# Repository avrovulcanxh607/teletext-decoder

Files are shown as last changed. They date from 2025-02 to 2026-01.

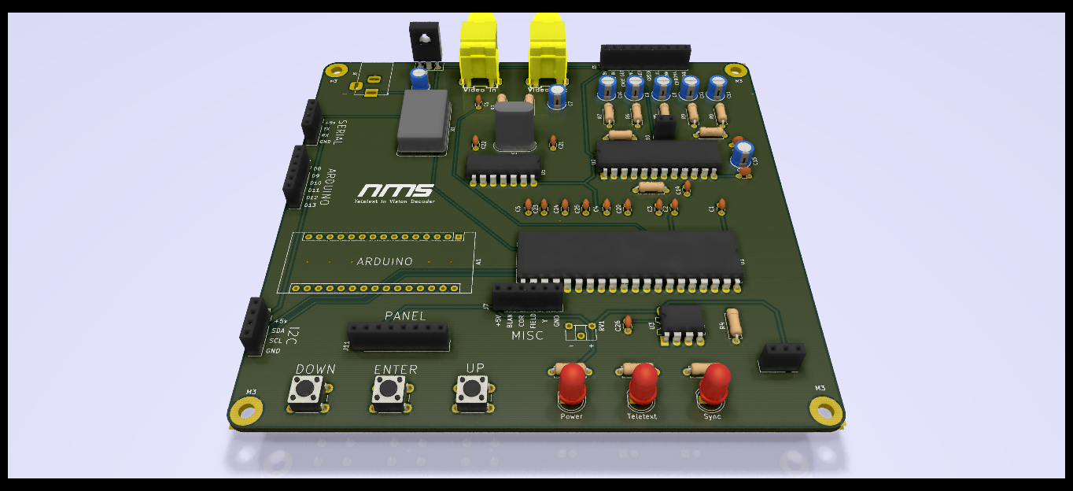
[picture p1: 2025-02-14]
PCB Files/COMPONENTS.png

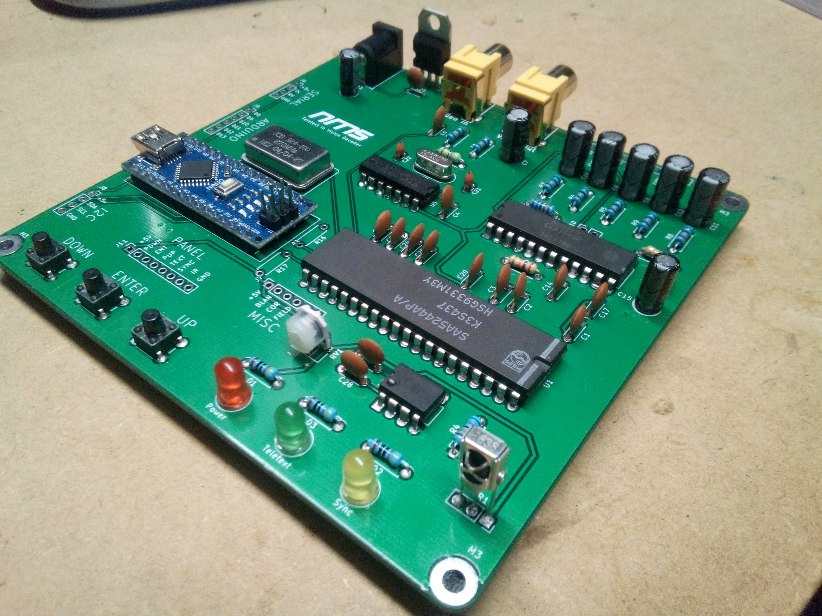
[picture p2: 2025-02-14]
PCB Files/IMG_20200507_191400.jpg

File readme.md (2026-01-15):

# Teletext In Vision Decoder Board

This repo is an attempt to open-source my teletext decoder.

It was originally designed, tested, and even a few were sold by me in 2019.

You can see the [original product page for it on my website](https://www.nathanmediaservices.co.uk/invision/).

You are now free to do whatever you like with this design and the firmware for it - except selling it. You are **expressly forbidden** to use these designs to create a product that you then go on to resell, unless I have given you written permission otherwise.

Disclaimer: the design and firmwares are offered completely as-is, with no warranty of any kind. I will no longer be offering support or assistance on this project, if you want to build one you must figure it out from the resources provided here. 

## Why are there so many different firmwares?

Because I have built various slightly different boards into different projects and cases for different purposes, and with different ancillaries. For example, there are code bases here which support LCD screens, IR remotes, thumbwheel selectors, serial remotes, etc. You'll probably need to try a few and modify them to suit your needs.

## PCB Versions
There are three total versions of the decoder PCB. The first version was a prototype, and features a number of mistakes - I therefore do not recommend using it. Unless you're a complete masochist.

The first revision fixes the mistakes on the prototype and is ready to use. 

The second revision swaps the Arduino Nano for a standalone ATMega328(p) chip. This makes it cheaper and easier for manufacture, but harder for programming/debugging - therefore I don't recommend this revision for the novice.

## Notes
Depending on how you configure the ATMega328(p) in revision 2, you may omit the crystal Y2 and associated tuning capacitors.

You may also omit R17 and R18 - these are I2C pullup resistors, and I have yet to find a need for more pullup than already onboard the microcontroller.

You need not install the output circuitry for the S-Video or RGB outputs if you don't need those - on the other hand, if you only intend to use the RGB output you can probably get rid of the entire PAL coder circuit and just bridge the chip's RGB directly to the outputs.

Really, you only actually *need* the teletext decoder, video input circuitry, and the microcontroller - the rest depends on what you're using it for! I have shipped some very bare boards in specific circumstances!

Similarly, the board is designed to take a 9-15v DC input and regulate it down to 5v for operation - however, the LM7805 should really have a heatsink and can be unreliable. Personally I always bridge the regulator out and supply 5v directly from an external supply.

If you are having trouble getting colour to work on the PAL CVBS or S-Video outputs, you need to check the colour subcarrier frequency. Your crystal may require slightly different tuning capacitors. However I have found most TVs to be very forgiving of the subcarrier frequency.

If you do decide to do something cool with this design, please consider posting photos of it to Bluesky and tagging "@nmsni.co.uk", I would love to see it!

Also... consider kicking a quid or two my way at [Ko-Fi](https://ko-fi.com/avrovulcanxh607). It took a fair bit of time to figure this out.

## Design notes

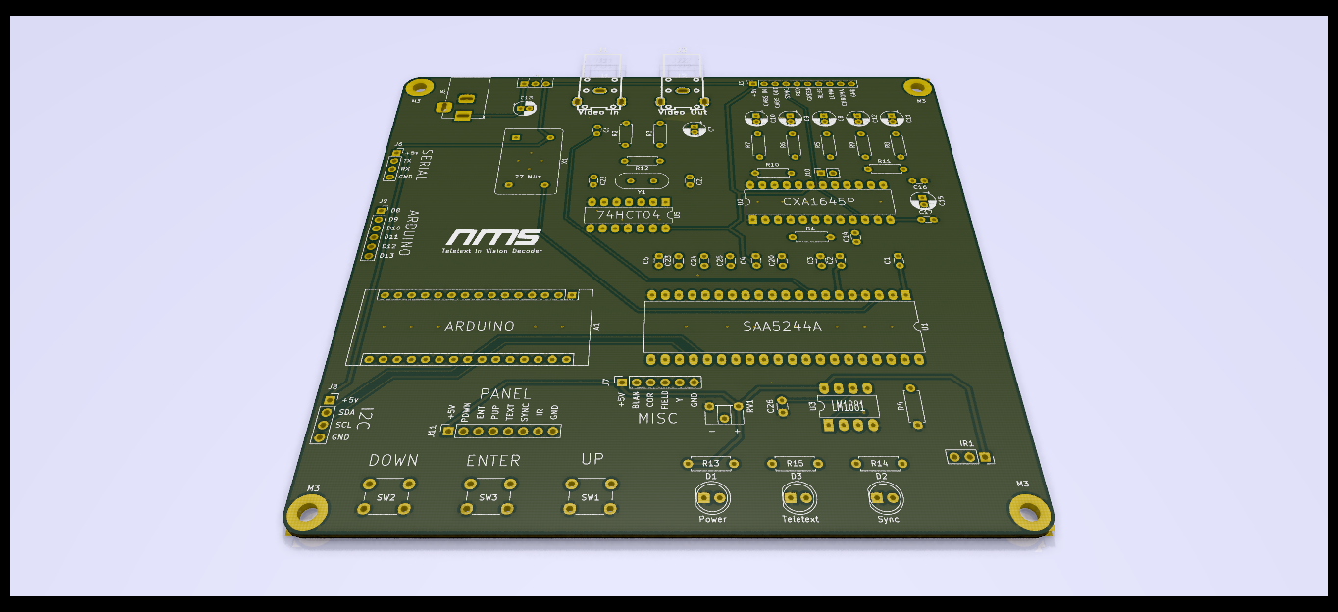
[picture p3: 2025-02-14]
PCB Files/BARE BOARD.png

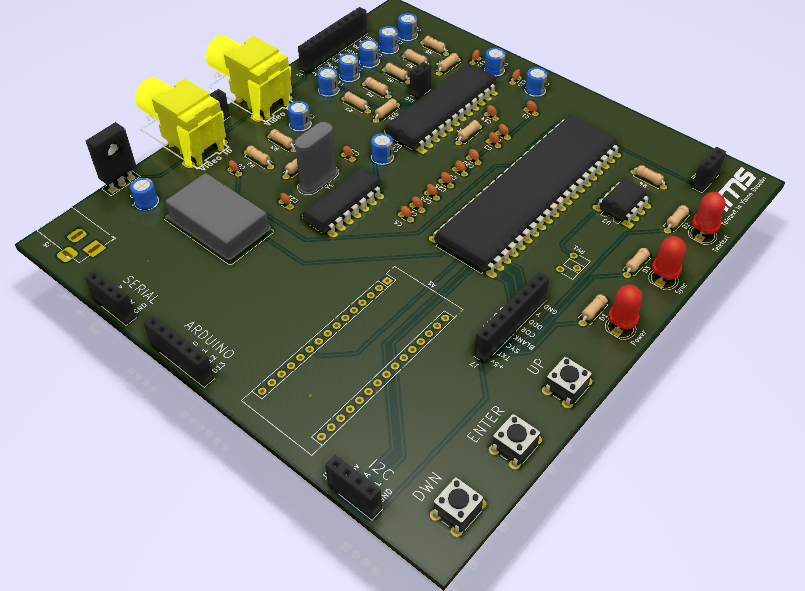
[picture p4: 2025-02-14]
PCB Files/Teletext In-Vision Decoder.png

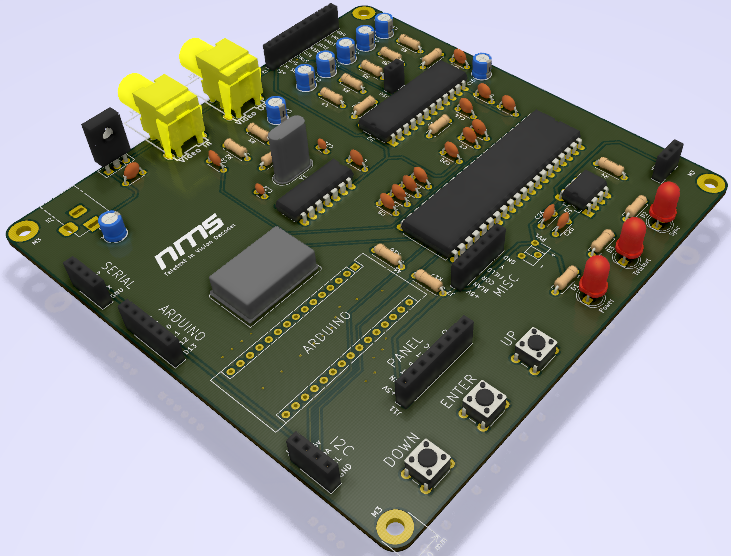
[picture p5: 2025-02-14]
PCB Files/pcbfordiag.png

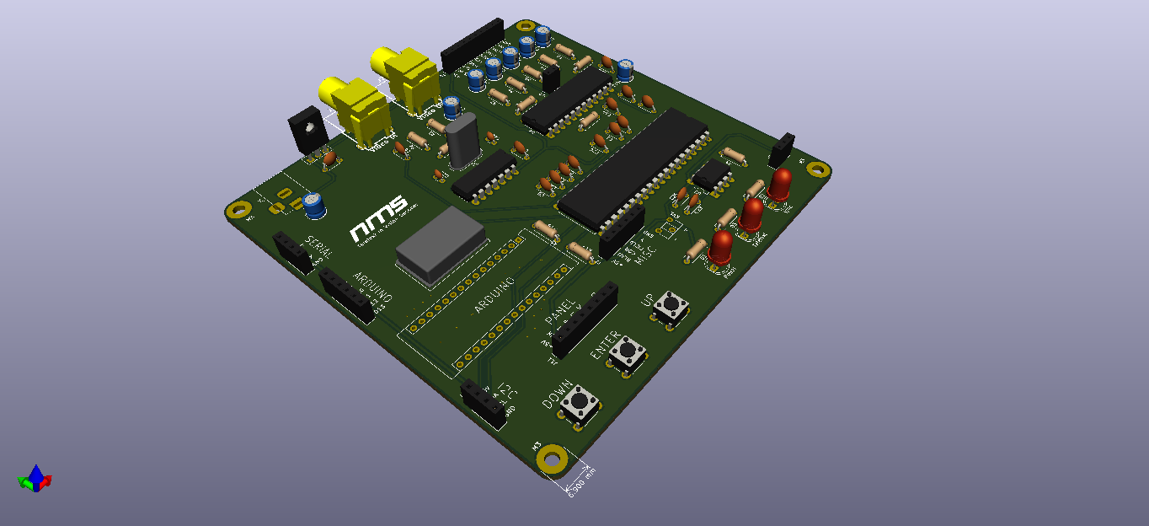
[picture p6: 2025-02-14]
PCB Files/pcbfordiag2.png

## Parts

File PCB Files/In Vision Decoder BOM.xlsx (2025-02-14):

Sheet: Per Reference
ref | value5 | footprint | part | description | names | tstamps6 | tstamp | datasheet | lib7 | part8 | alias | description9 | docs | fp | field | name10 | num | name11 | type | logical | uri | code | name12 | ref13 | pin
C1 | 100nF | Capacitor_THT:C_Disc_D3.0mm_W1.6mm_P2.50mm | C | Unpolarized capacitor
C14 | 100nF | Capacitor_THT:C_Disc_D3.0mm_W1.6mm_P2.50mm | C | Unpolarized capacitor
C16 | 100nF | Capacitor_THT:C_Disc_D3.0mm_W1.6mm_P2.50mm | C | Unpolarized capacitor
C17 | 100nF | Capacitor_THT:C_Disc_D3.0mm_W1.6mm_P2.50mm | C | Unpolarized capacitor
C2 | 100nF | Capacitor_THT:C_Disc_D3.0mm_W1.6mm_P2.50mm | C | Unpolarized capacitor
C20 | 100nF | Capacitor_THT:C_Disc_D3.0mm_W1.6mm_P2.50mm | C | Unpolarized capacitor
C23 | 100nF | Capacitor_THT:C_Disc_D3.0mm_W1.6mm_P2.50mm | C | Unpolarized capacitor
C24 | 100nF | Capacitor_THT:C_Disc_D3.0mm_W1.6mm_P2.50mm | C | Unpolarized capacitor
C25 | 100nF | Capacitor_THT:C_Disc_D3.0mm_W1.6mm_P2.50mm | C | Unpolarized capacitor
C26 | 100nf | Capacitor_THT:C_Disc_D3.0mm_W1.6mm_P2.50mm | C | Unpolarized capacitor
C27 | 100nF | Capacitor_THT:C_Disc_D3.0mm_W1.6mm_P2.50mm | C | Unpolarized capacitor
C3 | 100nF | Capacitor_THT:C_Disc_D3.0mm_W1.6mm_P2.50mm | C | Unpolarized capacitor
C4 | 100nF | Capacitor_THT:C_Disc_D3.0mm_W1.6mm_P2.50mm | C | Unpolarized capacitor
C5 | 100nF | Capacitor_THT:C_Disc_D3.0mm_W1.6mm_P2.50mm | C | Unpolarized capacitor
C6 | 100nF | Capacitor_THT:C_Disc_D3.0mm_W1.6mm_P2.50mm | C | Unpolarized capacitor
R16 | 10k | Resistor_THT:R_Axial_DIN0207_L6.3mm_D2.5mm_P7.62mm_Horizontal | R | Resistor
R17 | 10k | Resistor_THT:R_Axial_DIN0207_L6.3mm_D2.5mm_P7.62mm_Horizontal | R | Resistor
RV1 | 10k | Potentiometer_THT:Potentiometer_ACP_CA6-H2,5_Horizontal | R_POT | Potentiometer
C13 | 10uF | Capacitor_THT:CP_Radial_D5.0mm_P2.00mm | CP | Polarized capacitor
C15 | 10uF | Capacitor_THT:CP_Radial_D5.0mm_P2.00mm | CP | Polarized capacitor
R10 | 16k | Resistor_THT:R_Axial_DIN0207_L6.3mm_D2.5mm_P7.62mm_Horizontal | R | Resistor
R13 | 1k | Resistor_THT:R_Axial_DIN0207_L6.3mm_D2.5mm_P7.62mm_Horizontal | R | Resistor
R14 | 1k | Resistor_THT:R_Axial_DIN0207_L6.3mm_D2.5mm_P7.62mm_Horizontal | R | Resistor
R15 | 1k | Resistor_THT:R_Axial_DIN0207_L6.3mm_D2.5mm_P7.62mm_Horizontal | R | Resistor
C10 | 220uF | Capacitor_THT:CP_Radial_D5.0mm_P2.00mm | CP | Polarized capacitor
C11 | 220uF | Capacitor_THT:CP_Radial_D5.0mm_P2.00mm | CP | Polarized capacitor
C12 | 220uF | Capacitor_THT:CP_Radial_D5.0mm_P2.00mm | CP | Polarized capacitor
C7 | 220uF | Capacitor_THT:CP_Radial_D5.0mm_P2.00mm | CP | Polarized capacitor
C8 | 220uF | Capacitor_THT:CP_Radial_D5.0mm_P2.00mm | CP | Polarized capacitor
C9 | 220uF | Capacitor_THT:CP_Radial_D5.0mm_P2.00mm | CP | Polarized capacitor
R1 | 27k | Resistor_THT:R_Axial_DIN0207_L6.3mm_D2.5mm_P7.62mm_Horizontal | R | Resistor
C21 | 33pF | Capacitor_THT:C_Disc_D3.0mm_W1.6mm_P2.50mm | C | Unpolarized capacitor
C22 | 33pF | Capacitor_THT:C_Disc_D3.0mm_W1.6mm_P2.50mm | C | Unpolarized capacitor
Y1 | 4.43 MHz | Crystal:Crystal_HC49-U_Vertical | Crystal | Two pin crystal
R12 | 4.7M | Resistor_THT:R_Axial_DIN0207_L6.3mm_D2.5mm_P7.62mm_Horizontal | R | Resistor
R11 | 47k | Resistor_THT:R_Axial_DIN0207_L6.3mm_D2.5mm_P7.62mm_Horizontal | R | Resistor
R4 | 680k | Resistor_THT:R_Axial_DIN0207_L6.3mm_D2.5mm_P7.62mm_Horizontal | R | Resistor
U5 | 74HCT04 | Package_DIP:DIP-14_W7.62mm_LongPads | 74HCT04 | Hex Inverter
R2 | 75R | Resistor_THT:R_Axial_DIN0207_L6.3mm_D2.5mm_P7.62mm_Horizontal | R | Resistor
R3 | 75R | Resistor_THT:R_Axial_DIN0207_L6.3mm_D2.5mm_P7.62mm_Horizontal | R | Resistor
R5 | 75R | Resistor_THT:R_Axial_DIN0207_L6.3mm_D2.5mm_P7.62mm_Horizontal | R | Resistor
R6 | 75R | Resistor_THT:R_Axial_DIN0207_L6.3mm_D2.5mm_P7.62mm_Horizontal | R | Resistor
R7 | 75R | Resistor_THT:R_Axial_DIN0207_L6.3mm_D2.5mm_P7.62mm_Horizontal | R | Resistor
R8 | 75R | Resistor_THT:R_Axial_DIN0207_L6.3mm_D2.5mm_P7.62mm_Horizontal | R | Resistor
R9 | 75R | Resistor_THT:R_Axial_DIN0207_L6.3mm_D2.5mm_P7.62mm_Horizontal | R | Resistor
J9 | ARDUINO | Connector_PinSocket_2.54mm:PinSocket_1x06_P2.54mm_Vertical | Conn_01x06_Male
A1 | Arduino_Nano_v3.x | Module:Arduino_Nano | Arduino_Nano_v3.x | Arduino Nano v3.x
U2 | CXA1645P | Package_DIP:DIP-24_W10.16mm_LongPads | CXA1645P
X1 | CXO_DIP14 | Oscillator:Oscillator_DIP-14 | CXO_DIP14 | Crystal Clock Oscillator, DIP14-style metal package
SW3 | ENTER | Button_Switch_THT:SW_PUSH_6mm | SW_Push | Push button switch, generic, two pins
J8 | I2C | Connector_PinSocket_2.54mm:PinSocket_1x04_P2.54mm_Vertical | Conn_01x04_Male
IR1 | IR Receiver | Connector_PinSocket_2.54mm:PinSocket_1x03_P2.54mm_Vertical | Conn_01x03_Male
U4 | L7805 | Package_TO_SOT_THT:TO-126-3_Vertical | L7805 | Positive 1.5A 35V Linear Regulator, Fixed Output 5V, TO-220/TO-263/TO-252
U3 | LM1881 | Package_DIP:DIP-8_W7.62mm_LongPads | LM1881
J7 | MISC | Connector_PinSocket_2.54mm:PinSocket_1x06_P2.54mm_Vertical | Conn_01x06_Male
J11 | PANEL | Connector_PinSocket_2.54mm:PinSocket_1x08_P2.54mm_Vertical | Conn_01x08_Male
SW2 | PDWN | Button_Switch_THT:SW_PUSH_6mm | SW_Push | Push button switch, generic, two pins
D1 | POWER | LED_THT:LED_D5.0mm | LED | Light emitting diode
J5 | POWER IN | Connector_BarrelJack:BarrelJack_Horizontal | Barrel_Jack_MountingPin | DC Barrel Jack with a mounting pin
SW1 | PUP | Button_Switch_THT:SW_PUSH_6mm | SW_Push | Push button switch, generic, two pins
U1 | SAA5244A | Package_DIP:DIP-40_W15.24mm_LongPads | SAA5244A
J6 | SERIAL | Connector_PinSocket_2.54mm:PinSocket_1x04_P2.54mm_Vertical | Conn_01x04_Male
D2 | SYNC | LED_THT:LED_D5.0mm | LED | Light emitting diode
D3 | TEXT | LED_THT:LED_D5.0mm | LED | Light emitting diode
J3 | VIDEO | Connector_PinSocket_2.54mm:PinSocket_1x10_P2.54mm_Vertical | Conn_01x10_Male
J1 | Video In | AV Connectors:rca_yellow | Conn_Coaxial | coaxial connector (BNC, SMA, SMB, SMC, Cinch/RCA, ...)
J2 | Video Out | AV Connectors:rca_yellow | Conn_Coaxial | coaxial connector (BNC, SMA, SMB, SMC, Cinch/RCA, ...)
J10 | Y TRAP | Connector_PinSocket_2.54mm:PinSocket_1x02_P2.54mm_Vertical | Conn_01x02_Male

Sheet: Per Value
 | Boards In Run: | 4 | Boards Completed: | 0 | Boards Sold: | 0
Ref | Value | Required (per board) | Required (per run) | Available | Excess/Short | Price (per run) | Price (per board)
C1 C2 C3 C4 C5 C6 C14 C16 C17 C20 C23 C24 C25 C26 C27 C28 | 100nF | 15 | 60 | 100 | 40 | £1.98 | £0.49
C13 C15 | 10uF | 2 | 8 | 25 | 17 | £0.99 | £0.25
C7 C8 C9 C10 C11 C12 | 220uF | 6 | 24 | 50 | 26 | £2.28 | £0.57
C21 C22 | 33pF | 2 | 8 | 20 | 12 | £1.29 | £0.32
R2 R3 R5 R6 R7 R8 R9 | 75R | 7 | 28 | 25 | -3 | £0.99 | £0.25
R13 R14 R15 | 1K | 3 | 12 | 24 | 12 | £0.99 | £0.25
R16 R17 | 10K | 2 | 8 | 0 | -8 | £0.99 | £0.25
R10 | 16K | 1 | 4 | 16 | 12 | £0.99 | £0.25
R1 | 27K | 1 | 4 | 12 | 8 | £0.99 | £0.25
R12 | 4.7M | 1 | 4 | 0 | -4 | £0.99 | £0.25
R11 | 47K | 1 | 4 | 7 | 3 | £0.99 | £0.25
R4 | 680K | 1 | 4 | 21 | 17 | £0.99 | £0.25
RV1 | 10K | 1 | 4 | 3 | -1 | £0.99 | £0.25
CXA1645P |  | 1 | 4 | 3 | -1 | £5.00 | £1.25
L7805 |  | 1 | 4 | 5 | 1 | £1.66 | £0.41
LM1881 |  | 1 | 4 | 4 | 0 | £5.00 | £1.25
SAA5244A |  | 1 | 4 | 7 | 3 | £22.16 | £5.54
74HCT04 |  | 1 | 4 | 10 | 6 | £2.24 | £0.56
Arduino Nano |  | 1 | 4 | 10 | 6 | £17.01 | £4.25
IR Receiver |  | 1 | 4 | 5 | 1 | £2.10 | £0.53
27MHz Oscillator |  | 1 | 4 | 5 | 1 | £14.90 | £3.73
4.43MHz Crystal |  | 1 | 4 | 6 | 2 | £12.24 | £3.06
LEDs |  | 3 | 12 | 30 | 18 | £5.00 | £1.25
Tactile Buttons |  | 3 | 12 | 20 | 8 | £3.49 | £0.87
Power Sockets |  | 1 | 4 | 10 | 6 | £3.49 | £0.87
Phono Sockets |  | 2 | 8 | 10 | 2 | £2.99 | £0.75
PCB |  | 1 | 4 | 10 | 6 | £13.39 | £3.35
TOTAL |  | 62.00 |  |  |  | £126.12 | £31.53
Recommended Price given profit margin |  | £215 | £53.75
Profit at recommended price |  | £88.88
Profit margin | 1.70
 |  |  | £5.00 | 1
 | Parts | Shipping | Me
Percentages | 0.587 | 0.023 | 0.390

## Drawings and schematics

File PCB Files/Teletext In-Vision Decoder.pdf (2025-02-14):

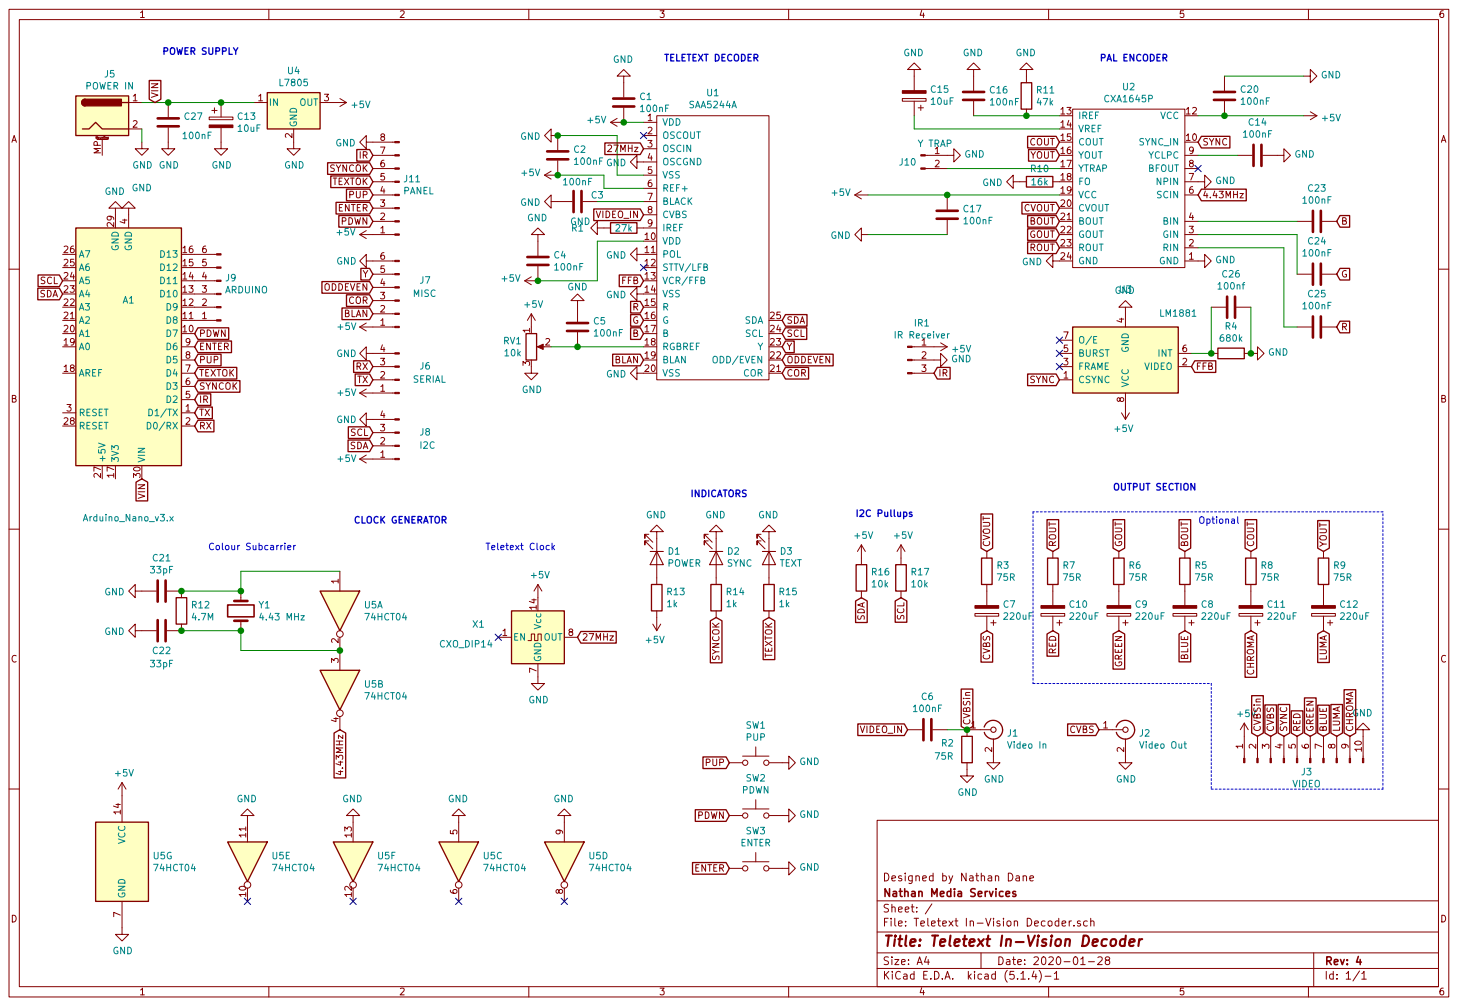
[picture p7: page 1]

FFB ROUTROUT GOUT SYNC

Optional I2C Pullups Teletext Clock

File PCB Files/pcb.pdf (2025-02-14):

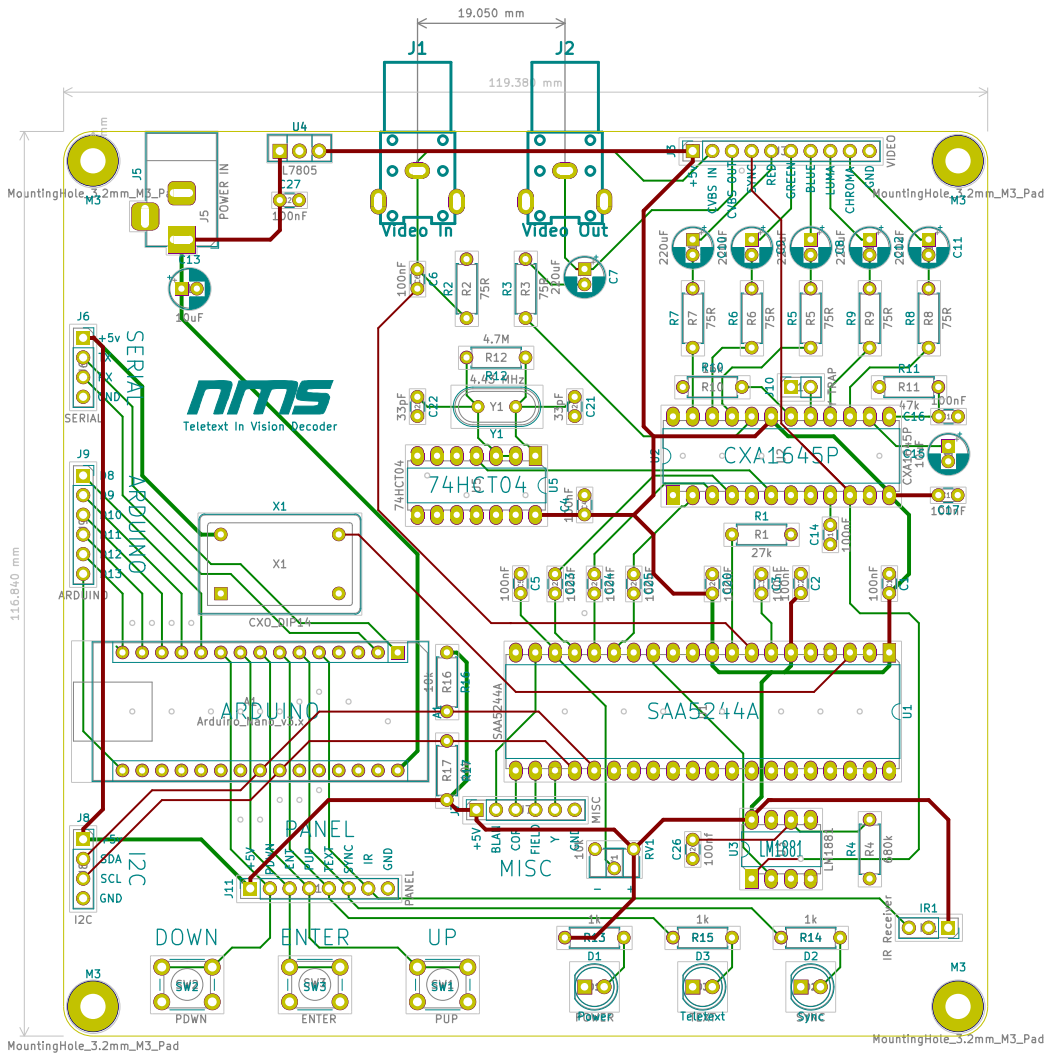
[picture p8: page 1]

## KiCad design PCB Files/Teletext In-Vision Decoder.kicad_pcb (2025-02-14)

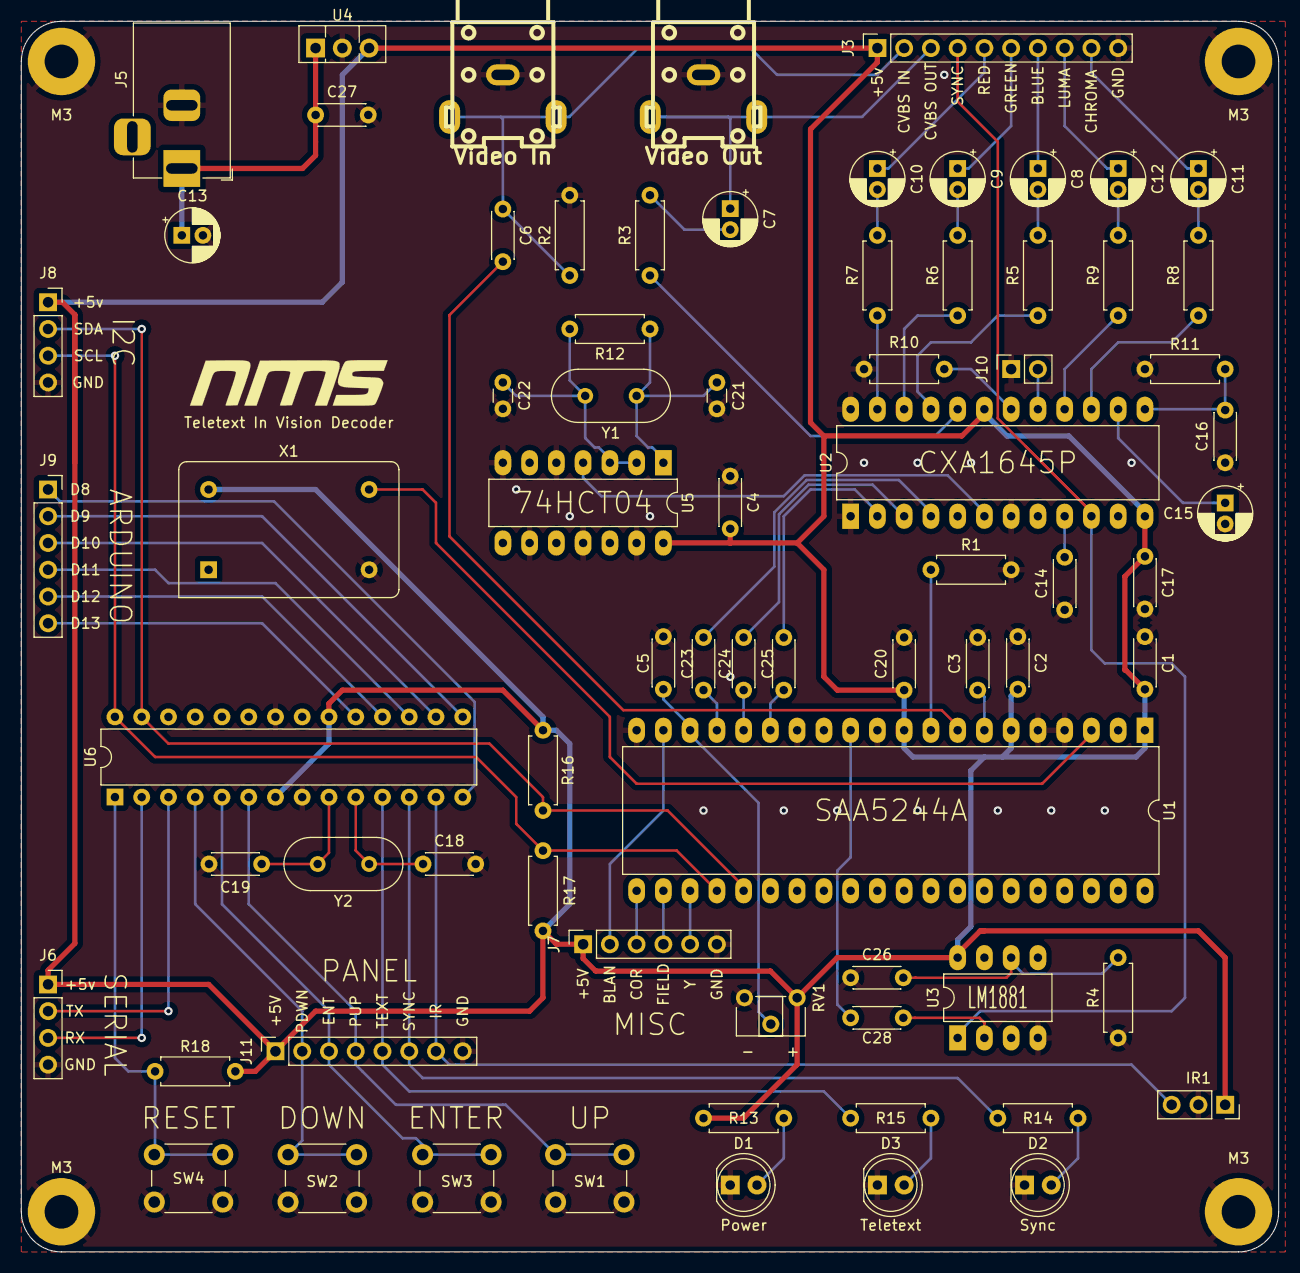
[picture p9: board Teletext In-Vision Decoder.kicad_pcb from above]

Board: 2 copper layers, 119.4 x 116.8 mm, 78 parts (0 on the bottom side), 71 nets.

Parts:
C1, C2, C3, C4, C5, C6, C14, C16, C17, C20, C23, C24, C25, C27, C28: 100nF; C_Disc_D4.3mm_W1.9mm_P5.00mm
C7, C8, C9, C10, C11, C12: 220uF; CP_Radial_D5.0mm_P2.00mm
C13, C15: 10uF; CP_Radial_D5.0mm_P2.00mm
C18, C19: C; C_Disc_D4.3mm_W1.9mm_P5.00mm
C21, C22: 33pF; C_Disc_D3.0mm_W1.6mm_P2.50mm
C26: 100nf; C_Disc_D4.3mm_W1.9mm_P5.00mm
D1: POWER; LED_D5.0mm
D2: SYNC; LED_D5.0mm
D3: TEXT; LED_D5.0mm
IR1: IR Receiver; PinSocket_1x03_P2.54mm_Vertical
J1: Video In; rca_yellow
J2: Video Out; rca_yellow
J3: VIDEO; PinSocket_1x10_P2.54mm_Vertical
J5: POWER IN; BarrelJack_Horizontal
J6: SERIAL; PinSocket_1x04_P2.54mm_Vertical
J7: MISC; PinSocket_1x06_P2.54mm_Vertical
J8: I2C; PinSocket_1x04_P2.54mm_Vertical
J9: ARDUINO; PinSocket_1x06_P2.54mm_Vertical
J10: Y TRAP; PinSocket_1x02_P2.54mm_Vertical
J11: PANEL; PinSocket_1x08_P2.54mm_Vertical
M3, M3#2, M3#3, M3#4: MountingHole_3.2mm_M3_Pad
R1: 27k; R_Axial_DIN0207_L6.3mm_D2.5mm_P7.62mm_Horizontal
R2, R3, R5, R6, R7, R8, R9: 75R; R_Axial_DIN0207_L6.3mm_D2.5mm_P7.62mm_Horizontal
R4: 680k; R_Axial_DIN0207_L6.3mm_D2.5mm_P7.62mm_Horizontal
R10: 16k; R_Axial_DIN0207_L6.3mm_D2.5mm_P7.62mm_Horizontal
R11: 47k; R_Axial_DIN0207_L6.3mm_D2.5mm_P7.62mm_Horizontal
R12: 4.7M; R_Axial_DIN0207_L6.3mm_D2.5mm_P7.62mm_Horizontal
R13, R14, R15: 1k; R_Axial_DIN0207_L6.3mm_D2.5mm_P7.62mm_Horizontal
R16, R17: 10k; R_Axial_DIN0207_L6.3mm_D2.5mm_P7.62mm_Horizontal
R18: R; R_Axial_DIN0207_L6.3mm_D2.5mm_P7.62mm_Horizontal
RV1: 10k; Potentiometer_ACP_CA6-H2,5_Horizontal
SW1: PUP; SW_PUSH_6mm
SW2: PDWN; SW_PUSH_6mm
SW3: ENTER; SW_PUSH_6mm
SW4: SW_Push; SW_PUSH_6mm
U1: SAA5244A; DIP-40_W15.24mm_LongPads
U2: CXA1645P; DIP-24_W10.16mm_LongPads
U3: LM1881; DIP-8_W7.62mm_LongPads
U4: L7805; TO-126-3_Vertical
U5: 74HCT04; DIP-14_W7.62mm_LongPads
U6: ATmega328-P; DIP-28_W7.62mm
X1: CXO_DIP14; Oscillator_DIP-14
Y1: 4.43 MHz; Crystal_HC49-U_Vertical
Y2: Crystal; Crystal_HC49-U_Vertical

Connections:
4.43MHz: U2.6 (SCIN), U5.4
27MHz: U1.3 (OSCIN), X1.8 (OUT)
+5V: C1.2, C2.2, C4.2, C17.1, C20.1, IR1.1, J3.1, J6.1, J7.1, J8.1, J11.1, R13.2, R16.1, R17.1, R18.2, RV1.1, U1.1 (VDD), U1.6 (REF+), U1.10 (VDD), U2.12 (VCC), U2.19 (VCC), U3.8 (VCC), U4.3 (OUT), U5.14 (VCC), U6.7 (VCC), U6.20 (AVCC), X1.14 (Vcc)
B: C23.1, U1.17 (B)
BLAN: J7.2, U1.19 (BLAN)
BLUE: C8.1, J3.7
BOUT: R5.1, U2.21 (BOUT)
CHROMA: C11.1, J3.9
COR: J7.3, U1.21 (COR)
COUT: R8.1, U2.15 (COUT)
CVBS: C7.1, J2.1 (In), J3.3
CVBSin: C6.1, J1.1 (In), J3.2, R2.1
CVOUT: R3.1, U2.20 (CVOUT)
ENTER: J11.3, SW3.1, U6.5 (PD3)
G: C24.1, U1.16 (G)
GND: C1.1, C2.1, C3.2, C4.1, C5.1, C13.2, C14.1, C15.2, C16.1, C17.2, C18.2, C19.2, C20.2, C21.2, C22.2, C26.1, C27.2, D1.1 (K), D2.1 (K), D3.1 (K), IR1.2, J1.2 (Ext), J2.2 (Ext), J3.10, J5.2, J6.4, J7.6, J8.4, J10.1, J11.8, M3.1, M3#2.1, M3#3.1, M3#4.1, R1.2, R2.2, R4.1, R10.2, R11.1, RV1.3, SW1.2, SW2.2, SW3.2, SW4.2, U1.4 (OSCGND), U1.5 (VSS), U1.11 (POL), U1.14 (VSS), U1.20 (VSS), U2.1 (GND), U2.7 (NPIN), U2.24 (GND), U3.4 (GND), U4.2 (GND), U5.5, U5.7 (GND), U5.9, U5.11, U5.13, U6.8 (GND), U6.22 (GND), X1.7 (GND)
GOUT: R6.1, U2.22 (GOUT)
GREEN: C9.1, J3.6
IR: IR1.3, J11.7, U6.13 (PD7)
LFB: C28.1, U1.12 (STTV/LFB)
LUMA: C12.1, J3.8
unnamed: C3.1, U1.7 (BLACK)
unnamed: C5.2, RV1.2, U1.18 (RGBREF)
unnamed: C7.2, R3.2
unnamed: C8.2, R5.2
unnamed: C9.2, R6.2
unnamed: C10.2, R7.2
unnamed: C11.2, R8.2
unnamed: C12.2, R9.2
unnamed: C14.2, U2.9 (YCLPC)
unnamed: C15.1, U2.14 (VREF)
unnamed: C16.2, R11.2, U2.13 (IREF)
unnamed: C18.1, U6.10 (XTAL2/PB7), Y2.1
unnamed: C19.1, U6.9 (XTAL1/PB6), Y2.2
unnamed: C21.1, R12.1, U5.1, Y1.1
unnamed: C22.1, R12.2, U5.2, U5.3, Y1.2
unnamed: C23.2, U2.4 (BIN)
unnamed: C24.2, U2.3 (GIN)
unnamed: C25.2, U2.2 (RIN)
unnamed: C26.2, R4.2, U3.6 (INT)
unnamed: C28.2, U3.2 (VIDEO)
unnamed: D1.2 (A), R13.1
unnamed: D2.2 (A), R14.1
unnamed: D3.2 (A), R15.1
unnamed: J10.2, U2.17 (YTRAP)
unnamed: R1.1, U1.9 (IREF)
unnamed: R10.1, U2.18 (FO)
unnamed: R18.1, SW4.1, U6.1 (~RESET/PC6)
unnamed: J9.1, U6.14 (PB0)
unnamed: J9.2, U6.15 (PB1)
unnamed: J9.3, U6.16 (PB2)
unnamed: J9.4, U6.17 (PB3)
unnamed: J9.5, U6.18 (PB4)
unnamed: J9.6, U6.19 (PB5)
ODDEVEN: J7.4, U1.22 (ODD/EVEN)
PDWN: J11.2, SW2.1, U6.4 (PD2)
PUP: J11.4, SW1.1, U6.6 (PD4)
R: C25.1, U1.15 (R)
RED: C10.1, J3.5
ROUT: R7.1, U2.23 (ROUT)
RX: J6.3, U6.2 (PD0)
SCL: J8.3, R17.2, U1.24 (SCL), U6.28 (PC5)
SDA: J8.2, R16.2, U1.25 (SDA), U6.27 (PC4)
SYNC: J3.4, U2.10 (SYNC_IN), U3.1 (CSYNC)
SYNCOK: J11.6, R14.2, U6.12 (PD6)
TEXTOK: J11.5, R15.2, U6.11 (PD5)
TX: J6.2, U6.3 (PD1)
VIDEO_IN: C6.2, U1.8 (CVBS)
VIN: C13.1, C27.1, J5.1, U4.1 (IN)
Y: J7.5, U1.23 (Y)
YOUT: R9.1, U2.16 (YOUT)

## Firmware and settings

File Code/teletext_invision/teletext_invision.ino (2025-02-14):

#include <teletext.h>
#include <Wire.h>
#include <IRremote.h>
#include <EEPROM.h>
#include <PCF8574.h>

PCF8574 INPUTS(0x38);
PCF8574 LED(0x39);

IRrecv irrecv(2);
decode_results results;
Teletext teletext;
void(* resetFunc) (void) = 0;

int i=1,p=1,Mag=1,Pten=0,Punit=0,command=0;
bool check=true,pblf=false,newCom=false;

long eepromReadLong(long address)
{
      // Read the 4 bytes from the eeprom memory.
      long four = EEPROM.read(address);
      long three = EEPROM.read(address + 1);
      long two = EEPROM.read(address + 2);
      long one = EEPROM.read(address + 3);

      // Return the recomposed long by using bitshift.
      return ((four << 0) & 0xFF) + ((three << 8) & 0xFFFF) + ((two << 16) & 0xFFFFFF) + ((one << 24) & 0xFFFFFFFF);
}

void eepromWriteLong(int address, long value)
{
      //Decomposition from a long to 4 bytes by using bitshift.
      //One = Most significant -> Four = Least significant byte
      byte four = (value & 0xFF);
      byte three = ((value >> 8) & 0xFF);
      byte two = ((value >> 16) & 0xFF);
      byte one = ((value >> 24) & 0xFF);

      //Write the 4 bytes into the eeprom memory.
      EEPROM.write(address, four);
      EEPROM.write(address + 1, three);
      EEPROM.write(address + 2, two);
      EEPROM.write(address + 3, one);
}


long IR_ZERO= eepromReadLong(4);
long IR_ONE=  eepromReadLong(8);
long IR_TWO=  eepromReadLong(12);
long IR_THREE=eepromReadLong(16);
long IR_FOUR= eepromReadLong(20);
long IR_FIVE= eepromReadLong(24);
long IR_SIX=  eepromReadLong(28);
long IR_SEVEN=eepromReadLong(32);
long IR_EIGHT=eepromReadLong(36);
long IR_NINE= eepromReadLong(40);

long IR_UP=   eepromReadLong(44);
long IR_DOWN= eepromReadLong(56);
long IR_ENTER=eepromReadLong(60);

void setup() {
  if (!LED.begin())
  {
    Serial.println("could not initialize...");
  }
  if (!INPUTS.begin())
  {
    Serial.println("could not initialize...");
  }
  
  if (!LED.isConnected())
  {
    Serial.println("=> not connected");
  }
  else
  {
    Serial.println("=> connected!!");
  }

  if (!INPUTS.isConnected())
  {
    Serial.println("=> not connected");
  }
  else
  {
    Serial.println("=> connected!!");
  }
  teletext.writeByte(0x09,0x40);  // Clear Memory in case of reset
  delay(1000);  // Give it a chance to clear the memory
  irrecv.enableIRIn();
  pinMode(3, OUTPUT);
  pinMode(4, OUTPUT);
  pinMode(5,INPUT_PULLUP);
  pinMode(6,INPUT_PULLUP);
  pinMode(7,INPUT_PULLUP);
  Serial.begin(9600);
  Serial.println("Teletext In-Vision Decoder");
  Wire.beginTransmission (0x11);
  if (Wire.endTransmission () != 0)
  {
    Serial.println("SAA5244 absent or faulty!");
    while(true)
    {
      digitalWrite(3,HIGH); // Flash LEDs if the chip's broken
      digitalWrite(4,LOW);
      delay(500);
      digitalWrite(4,HIGH);
      digitalWrite(3,LOW);
      delay(500);
    }
  }
  teletext.begin();
  if(digitalRead(6)==LOW)
  {
    setupMenu();
  }
  waitmsg();
  textmsg();
  Serial.println("Waiting for teletext...");
  while(!teletext.status()) { // Don't do anything until we get a decent teletext signal
    delay(100);
  }
  waitmsg();
  packetmsg();
  Serial.println("Waiting for 8/30...");
  int sec=0;
  while(!teletext.callInit()) { // wait to get 8/30
    delay(20);  // Check every field
    sec++;
    if(sec>200)  // No packet 8/30 for 4 seconds? (should be one every second(?))
    {
      Serial.println("No 8/30, calling P100");
      teletext.callPage(1,0,0); // By default, call P100 if there's no 8/30 for whatever reason
      break;  // Stop waiting for 8/30
    }
  }
}

void loop() {
  teletext.status();
  int pup = digitalRead(5);
  int ent = digitalRead(6);
  int pdn = digitalRead(7);
  
  pblf = teletext.pblf();  // Read PBLF (Page Being Looked For)
  if(pblf && check) // If a P(i)BLF and the check flag is true
    check=false;    // It's wrong. This is a new page and will need to be checked again.
  if(!pblf && !check) // If the page is found and we haven't checked it...
  {
    delay(40); // Give it a sec to read in the page
    teletext.checkX24();  // Check it!
    check=true; // Ok, we've checked it now
  }
  
  // Here is where you can enter commands to be processed by the control loop
  // The higher up the list a command is, the higher it's priority

  if (!newCom && Serial.available())  // Serial Always takes priority
  {
    newCom=true;
    command=Serial.read();
    Serial.write(command);
  }
  if (!newCom && irrecv.decode(&results)) // IR takes priority over buttons
  {
    if(results.value==IR_ONE)
    {
      newCom=true;
      command=49;
    }
    if(results.value==IR_TWO)
    {
      newCom=true;
      command=50;
    }
    if(results.value==IR_THREE)
    {
      newCom=true;
      command=51;
    }
    if(results.value==IR_FOUR)
    {
      newCom=true;
      command=52;
    }
    if(results.value==IR_FIVE)
    {
      newCom=true;
      command=53;
    }
    if(results.value==IR_SIX)
    {
      newCom=true;
      command=54;
    }
    if(results.value==IR_SEVEN)
    {
      newCom=true;
      command=55;
    }
    if(results.value==IR_EIGHT)
    {
      newCom=true;
      command=56;
    }
    if(results.value==IR_NINE)
    {
      newCom=true;
      command=57;
    }
    if(results.value==IR_ZERO)
    {
      newCom=true;
      command=48;
    }
    if(results.value==IR_UP)
    {
      newCom=true;
      command=43;
    }
    if(results.value==IR_DOWN)
    {
      newCom=true;
      command=45;
    }
    if(results.value==IR_ENTER)
    {
      newCom=true;
      command=13;
    }
    if(results.value==0xFFFFFFFF) // If the button is still being held, repeat the last command
    {
      newCom=true;
    }
    irrecv.resume(); // Receive the next value
  }
  if (!newCom && ent == LOW) // Enter button
  {
    newCom=true;
    command=13; // Trigger a command
  }
  if (!newCom && pup == LOW) // Page up button
  {
    newCom=true;
    command=43;
  }
  if (!newCom && pdn == LOW) // Page down button
  {
    newCom=true;
    command=45; 
  }

  // This is the command loop. Don't mess with it if you don't know what you're doing!
  // Changing values here will break serial and remote control.
  // If there's a new command, read it and do whatever needs done
  if (newCom){
    if (isDigit(command))
    {
      command = command-48;
      if (p == 1)
      {
        teletext.setCursor(0x00,0x00);
        teletext.writeByte(0x0b,0x01);
        teletext.writeByte(0x0b,0x50);
        teletext.writeByte(0x0b,0x20);
        teletext.writeByte(0x0b,0x20); // Clear the status line
        teletext.writeByte(0x0b,0x20);
        teletext.setCursor(0x00,0x02);
      }
      if (p == 1)
      {
        teletext.setCursor(0x00,0x02);
        teletext.writeByte(0x0b,command+48);
        Mag = (int)command;
      }
      if (p == 2)
      {
        teletext.setCursor(0x00,0x03);
        teletext.writeByte(0x0b,command+48);
        Pten = (int)command;
      }
      if (p == 3)
      {
        teletext.setCursor(0x00,0x04);
        teletext.writeByte(0x0b,command+48);
        Punit = (int)command;
      }
      p++;
      if (p > 3)
      {
        p = 1;
      }
    }
    if (command == 13) // Carriage Return is Enter
    {
      teletext.callPage(Mag,Pten,Punit);
    }
    if (command == 43)  // Page Up
    {
      Punit++;
      if(Punit>9)
      {
        Punit=0;
        Pten++;
        if(Pten>9)
        {
          Pten=0;
          Mag++;
          if(Mag>8)
          {
            Mag=1;
          }
        }
      }
      teletext.setCursor(0x00,0x00);
      teletext.writeByte(0x0b,0x01); // red
      teletext.writeByte(0x0b,0x50); // P
      teletext.writeByte(0x0b,Mag+48); 
      teletext.writeByte(0x0b,Pten+48); // Write the Page status on row 0
      teletext.writeByte(0x0b,Punit+48);
    }
    if (command == 45) 
    {  // Page Down
      if(Punit==0)
      {
        if(Pten==0)
        {
          if(Mag==1)
          {
            Mag=8;
            Punit=9;
            Pten=9;
          }
          else
          {
            Mag--;
            Punit=9;
            Pten=9;
          }
        }
        else
        {
          Pten--;
          Punit=9;
        }
      }
      else
        Punit--;
      teletext.setCursor(0x00,0x00);
      teletext.writeByte(0x0b,0x01); // red
      teletext.writeByte(0x0b,0x50); // P
      teletext.writeByte(0x0b,Mag+48); 
      teletext.writeByte(0x0b,Pten+48); // Write the Page status on row 0
      teletext.writeByte(0x0b,Punit+48);
    }
    newCom=false;
  }
  delay(100);
}

void waitmsg()  // Surely there's a better way to do this!??
{
  int textLine[29]  = {0x03,0x20,0x20,0x20,0x4e,0x4d,0x53,0x20,0x28,0x32,0x30,0x32,0x30,0x29,0x08,0x20,0x20,0x57,0x61,0x69,0x74,0x69,0x6e,0x67,0x20,0x66,0x6f,0x72,0x20};
  teletext.setCursor(0,0);
  teletext.writeByte(0x00,0x00);
  for (int i=0; i<sizeof textLine/sizeof textLine[0]; i++) {
      int s = textLine[i];
      teletext.writeByte(0x0b,s);
  }
}

void textmsg()
{
  int textLine[11]  = {0x74,0x65,0x6c,0x65,0x74,0x65,0x78,0x74,0x2e,0x2e,0x2e};
  for (int i=0; i<sizeof textLine/sizeof textLine[0]; i++) {
      int s = textLine[i];
      teletext.writeByte(0x0b,s);
  }
}

void packetmsg()
{
  int textLine[11]  = {0x38,0x2f,0x33,0x30,0x2e,0x2e,0x2e,0x20,0x20,0x20,0x20};
  for (int i=0; i<sizeof textLine/sizeof textLine[0]; i++) {
      int s = textLine[i];
      teletext.writeByte(0x0b,s);
  }
}

void fasttextMenu()
{
  int settings = EEPROM.read(0);
  char string[4] = "Off ";
  if(bitRead(settings,0)==1) strcpy(string, "Auto");
  teletext.setCursor(3,30);
  for(int i =0; i < strlen(string); i++ ) {
    char c = string[i];
    teletext.writeByte(0x0b,c);
  }
}

void setupMenu()
{
  Serial.println("Setup Mode - use the onboard buttons");
  teletext.writeByte(0x01,36);  // Turn off acquisition
  int settings = EEPROM.read(0);
  fillscreen();
  drawMenu();
  fasttextMenu();
  int menupos=0;
  while(digitalRead(6)==LOW) delay(200);  // Debounce - Don't activate the menu until enter's been released
  while(true)
  {
    if(digitalRead(5)==LOW)
    {
      if(menupos<2) menupos++;
    }
    if(digitalRead(7)==LOW)
    {
      if(menupos>0) menupos--;
    }
    if(digitalRead(6)==LOW)
    {
      if(menupos==0)  // Pair Remote
      {
        Serial.println("Pairing new remote");
        pairIR();
        delay(2000);
        resetFunc();
      }
      if(menupos==1)  // Fasttext
      {
        if(bitRead(settings,0)==1) bitClear(settings,0);
        else bitSet(settings,0);
        EEPROM.update(0, settings);
        fasttextMenu();
      }
      if(menupos==2)
      {
        teletext.colourBars();
        while(true) delay(5000);
      }
    }
    teletext.setCursor((menupos+1),0);
    teletext.writeByte(0x0b,0x04);
    teletext.setCursor((menupos+2),0);
    teletext.writeByte(0x0b,0x01);
    teletext.setCursor((menupos+3),0);
    teletext.writeByte(0x0b,0x04);
    delay(200);
  }
}

void drawMenu()
{
  teletext.setCursor(0,0);
  int text2Line[18]  = {0x07,0x1d,0x00,0x53,0x79,0x73,0x74,0x65,0x6d,0x20,0x73,0x65,0x74,0x74,0x69,0x6e,0x67,0x73};
  for (int i=0; i<sizeof text2Line/sizeof text2Line[0]; i++) {
    int s = text2Line[i];
    teletext.writeByte(0x0b,s);
  }
  teletext.setCursor(2,3);
  char string[] = "Pair IR remote";
  for(int i =0; i < strlen(string); i++ ) {
    char c = string[i];
    teletext.writeByte(0x0b,c);
  }
  teletext.setCursor(3,3);
  strcpy(string, "Fasttext (row 24) display: ");
  for(int i =0; i < strlen(string); i++ ) {
    char c = string[i];
    teletext.writeByte(0x0b,c);
  }
  teletext.setCursor(4,3);
  strcpy(string, "Colour Bars");
  for(int i =0; i < strlen(string); i++ ) {
    char c = string[i];
    teletext.writeByte(0x0b,c);
  }
}

void fillscreen()
{
  teletext.writeByte(0x09,0x40);  // Clear Memory
  delay(100);
  for (int r=1; r<23; r++)
  {
    teletext.setCursor(r,0);
    teletext.writeByte(0x00,0x00);
    teletext.writeByte(0x0b,0x04);
    teletext.writeByte(0x0b,0x1d);
    teletext.writeByte(0x0b,0x03);
  }
  teletext.setCursor(21,2);
  teletext.writeByte(0x0b,0x06);
  char string[]="NMS (c) V1.0 May 2020";
  for(int i =0; i < strlen(string); i++ ) {
    char c = string[i];
    teletext.writeByte(0x0b,c);
  }
}

void pairIR()
{
  fillscreen();
  teletext.setCursor(2,3);
  char string[] = "Press";
  for(int i =0; i < strlen(string); i++ ) {
    char c = string[i];
    teletext.writeByte(0x0b,c);
  }

  for(int i=0; i<=16; i++)
  {
    teletext.setCursor(2,9);
    if(i<10) teletext.writeByte(0x0b,(48+i));
    else if(i==10)
    {
      teletext.writeByte(0x0b,117); // up
      teletext.writeByte(0x0b,112);
    }
    else if(i==11)
    {
      teletext.writeByte(0x0b,114); // red
      teletext.writeByte(0x0b,101);
      teletext.writeByte(0x0b,100);
    }
    else if(i==12)
    {
      teletext.writeByte(0x0b,99);  // cyan
      teletext.writeByte(0x0b,121);
      teletext.writeByte(0x0b,97);
      teletext.writeByte(0x0b,110);
    }
    else if(i==13)
    {
      teletext.writeByte(0x0b,100); // down
      teletext.writeByte(0x0b,111);
      teletext.writeByte(0x0b,119);
      teletext.writeByte(0x0b,110);
    }
    else if(i==14)
    {
      teletext.writeByte(0x0b,101); // enter
      teletext.writeByte(0x0b,110);
      teletext.writeByte(0x0b,116);
      teletext.writeByte(0x0b,101);
      teletext.writeByte(0x0b,114);
    }
    else if(i==15)
    {
      teletext.writeByte(0x0b,103); // green
      teletext.writeByte(0x0b,114);
      teletext.writeByte(0x0b,101);
      teletext.writeByte(0x0b,101);
      teletext.writeByte(0x0b,110);
    }
    else if(i==16)
    {
      teletext.writeByte(0x0b,121); // yellow
      teletext.writeByte(0x0b,101);
      teletext.writeByte(0x0b,108);
      teletext.writeByte(0x0b,108);
      teletext.writeByte(0x0b,111);
      teletext.writeByte(0x0b,119);
    }
    irrecv.resume();
    while(!irrecv.decode(&results))
    {
      delay(100);
    }
    if(!sanityCheck(results.value))
    {
      i--;
    }
    else
    {
      eepromWriteLong(results.value,((i+1)*4));
    }
  }
  teletext.setCursor(4,2);
  teletext.writeByte(0x0b,0x02);
  teletext.writeByte(0x0b,79);
  teletext.writeByte(0x0b,75);
}

bool sanityCheck(unsigned long input)
{
  if(input > 0xFFFFFF) return false;
  if(input < 0x100000) return false;
  if(bitRead(input,0)==bitRead(input, 8)) return false;
  if(bitRead(input,1)==bitRead(input, 9)) return false;
  if(bitRead(input,2)==bitRead(input,10)) return false;
  if(bitRead(input,3)==bitRead(input,11)) return false;
  if(bitRead(input,4)==bitRead(input,12)) return false;
  if(bitRead(input,5)==bitRead(input,13)) return false;
  if(bitRead(input,6)==bitRead(input,14)) return false;
  if(bitRead(input,7)==bitRead(input,15)) return false;
  return true;
}

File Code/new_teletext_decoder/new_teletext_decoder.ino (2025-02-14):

/*
 * NMS Teletext In-Vision Decoder
 * TDE-1200 Rack-Mountable Model with LCD
*/

// Include various Libraries we'll need later
#include <Wire.h>
#include <EEPROM.h>
#include <PCF8574.h>
#include <LiquidCrystal_I2C.h>

// Define various Objects
PCF8574 INPUTS(0x38);
PCF8574 LED(0x39);
LiquidCrystal_I2C lcd(0x27,24,2);

int saa5244[9]={0,4,0,0,0,254,127,7,16};

int oldmag=99;
int oldpten=99;
int oldpunit=99;

bool overrideSelect=false;

byte thinP[] = {
  B00000,
  B00110,
  B00101,
  B00110,
  B00100,
  B00100,
  B00100,
  B00000
};

byte c4[] = {
  B01110,
  B10001,
  B10001,
  B00100,
  B00000,
  B00111,
  B00100,
  B11111
};

byte c5[] = {
  B01110,
  B10001,
  B10001,
  B00100,
  B00000,
  B10111,
  B10101,
  B11101
};

byte c6[] = {
  B01110,
  B10001,
  B10001,
  B00100,
  B00000,
  B11111,
  B10101,
  B11101
};

byte c7[] = {
  B01110,
  B10001,
  B10001,
  B00100,
  B00000,
  B00001,
  B00001,
  B11111
};

byte c8[] = {
  B01110,
  B10001,
  B10001,
  B00100,
  B00000,
  B11111,
  B10101,
  B11111
};

void setup() {
  bool fled=false;
  bool fin=false;
  bool text=false;

  LED.begin();  // Enable the front panel ICs
  INPUTS.begin();
  Serial.begin(9600); // Enable the Serial Port
  lcd.init(); // Enable the LCD & turn on its backlight
  lcd.backlight();
  
  lcd.setCursor(1,0); // Display Startup message
  lcd.print("Nathan Media Services");
  lcd.setCursor(3,1);
  lcd.print("TDE-1200 (c) 2021");
  Serial.println(F("TDE-1200 Teletext Decoder"));

  lcd.createChar(0, thinP);
  lcd.createChar(1, c4);
  lcd.createChar(2, c5);
  lcd.createChar(3, c6);  // Create our custom characters
  lcd.createChar(4, c7);
  lcd.createChar(5, c8);

  pinMode(3, OUTPUT); // Set up the board LEDs
  pinMode(4, OUTPUT);
  pinMode(13, OUTPUT);
  pinMode(5,INPUT_PULLUP);  // Set up the board buttons
  pinMode(6,INPUT_PULLUP);
  pinMode(7,INPUT_PULLUP);

  writeByte(0x09,0x40); // Clear the display menu
  
  delay(2000);  // Let us see the wonderful boot screen!
  
  // Begin Self-Test

  if (!LED.isConnected()) // Check the front panel I2C Expanders are working
    fled=true;

  if (!INPUTS.isConnected())
    fin=true;

  Wire.beginTransmission (0x11);    // Check the main IC is working
  if (Wire.endTransmission () != 0)
    text=true;

  selftest(fled,fin,text);  // Get test results

  delay(1000);  // Show them for a second or whatever
  lcd.clear();  // Clear the screen
  saainit();    // Fire up the decoder
}

void loop() {
  status();
  readBSDP();

  if(Serial.available())
  {
    int command=Serial.read();
    Serial.write(command);
    if(command==110)
    {
      fastText(0);
    }
    else if(command==111)
    {
      fastText(1);
    }
    else if(command==112)
    {
      fastText(2);
    }
    else if(command==113)
    {
      fastText(3);
    }
    else if(command==114)
    {
      fastText(4);
    }
    else if(command==109)
    {
      fastText(5);
    }
    else if(command==100)
    {
      doubleSize(1);
    }
    else if(command==105)
    {
      doubleSize(2);
    }
    else if(command==106)
    {
      doubleSize(0);
    }
  }

  if(!overrideSelect) // Only read from the rotary selector if something else hasn't set a page
  {
    LED.write(3,LOW);
    LED.write(2,HIGH);
    LED.write(1,HIGH);
    int newmag=readSelect();  // First Digit

    LED.write(3,HIGH);
    LED.write(2,LOW);
    int newpten=readSelect(); // Second Digit

    LED.write(2,HIGH);
    LED.write(1,LOW);
    int newpunit=readSelect();  // Third Digit

    if(newmag!=oldmag || newpten!=oldpten || newpunit!=oldpunit)  // If the value has changed since we last checked...
    {
      callPage(newmag,newpten,newpunit);  // Call the page
    
      oldmag=newmag;  // Store the values for next time
      oldpten=newpten;
      oldpunit=newpunit;
    }
  }
  delay(100);
}

int readSelect()
{
  if(!INPUTS.read(0))
    return 0;
  else if(!INPUTS.read(1))
    return 1;
  else if(!INPUTS.read(2))
    return 2;
  else if(!INPUTS.read(3))
    return 3;
  else if(!INPUTS.read(4))
    return 4;
  else if(!INPUTS.read(5))
    return 5;
  else if(!INPUTS.read(6))
    return 6;
  else if(!INPUTS.read(7))
    return 7;
  else if(!LED.read(7))
    return 8;
  else if(!LED.read(6))
    return 9;
  else
    return 1;
}

void saainit()
{
  for (int i=0; i<9; i++)
  {
    writeByte(i,saa5244[i]);
  }
}

bool callPage(int M, int T, int U)  // Calls a Page
{
  int pten,punit;
  pten=T+48;
  punit=U+48;
  
  if (T > 9)
    pten=T+55;
  if (U > 9)
    punit=U+55;
  
  if (M < 9 && M > 0)
  {
    setCursor(0x00,0x00);
    writeByte(0x0b,0x02); // 9space 0x07) (green 0x02)
    writeByte(0x0b,0x50); // P
    writeByte(0x0b,48+M); 
    writeByte(0x0b,pten); // Write the Page status on row 0
    writeByte(0x0b,punit);
    writeByte(0x0b,0x20);
    setCursor(0x00,0x02);
    
    if (M == 8)
    {
      M = 0;  // 8 becomes 0 because of binary stuff
    }
    
    writeByte(0x02,0x00);
    writeByte(0x03,24+M);
  
    writeByte(0x02,0x01);
    writeByte(0x03,16+T); // Write the page number to the register
  
    writeByte(0x02,0x02);
    writeByte(0x03,16+U);
    return true;
  }
  else  // If the value isn't valid, change the number red
  {
    setCursor(0x00,0x00);
    writeByte(0x0b,0x01); // red
    writeByte(0x0b,0x50); // P
    writeByte(0x0b,48+M); 
    writeByte(0x0b,pten); // Write the Page status on row 0
    writeByte(0x0b,punit);
    setCursor(0x00,0x02);
    return false;
  }
  
}

bool readBSDP()
{
  bitClear(saa5244[0],0);  // Make sure we're writing to 11A not 11B
  writeByte(0x00,saa5244[0]);

  setCursor(0x22,0x00);
  int Dc = readByte(0x0b);  // Read Designation Code
  int Unit = readByte(0x0b);  // Read Page Unit
  int Ten = readByte(0x0b); // Read Page Ten
  
  setCursor(0x22,0x04);
  int byte4 = readByte(0x0b);
  setCursor(0x22,0x06); // Read page Mag
  int byte6 = readByte(0x0b);

  lcd.setCursor(0,1);
  setCursor(0x22,0x14);  // Read Status Display
  for (int i = 0; i <= 19; i++) { // 20 Characters
    lcd.write(readByte(0x0b));
  }

  lcd.setCursor(16,0);
  setCursor(0,32);  // Read Header
  for (int i = 0; i <= 8; i++) {
    lcd.write(readByte(0x0b));
  }

  int M1 = bitRead(byte4,3);
  int M2 = bitRead(byte6,3);
  int M3 = bitRead(byte6,2);
  int Mag=0;
  if (M1 == 1)
    bitSet(Mag,0);
  if (M2 == 1)
    bitSet(Mag,2);  // Work out actual Mag
  if (M3 == 1)
    bitSet(Mag,1);
  if (Mag == 0)
    Mag=8;
  
  if(Mag > 0 && Mag < 9 && Ten < 10 && Unit < 10) // Make sure it all checks out
  {
    lcd.setCursor(20,1);
    lcd.write(0);
    lcd.print(Mag);
    lcd.print(Ten);
    lcd.print(Unit);
  }
}
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
